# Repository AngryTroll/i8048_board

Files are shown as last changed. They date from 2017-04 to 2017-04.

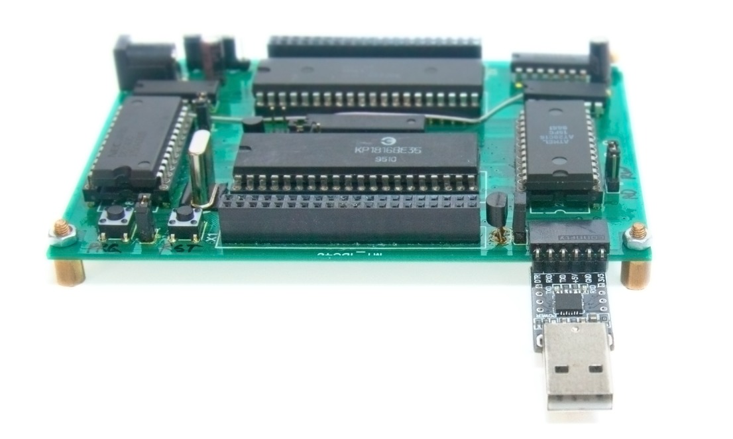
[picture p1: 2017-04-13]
pcad/rev_A/photos/3_1.jpg

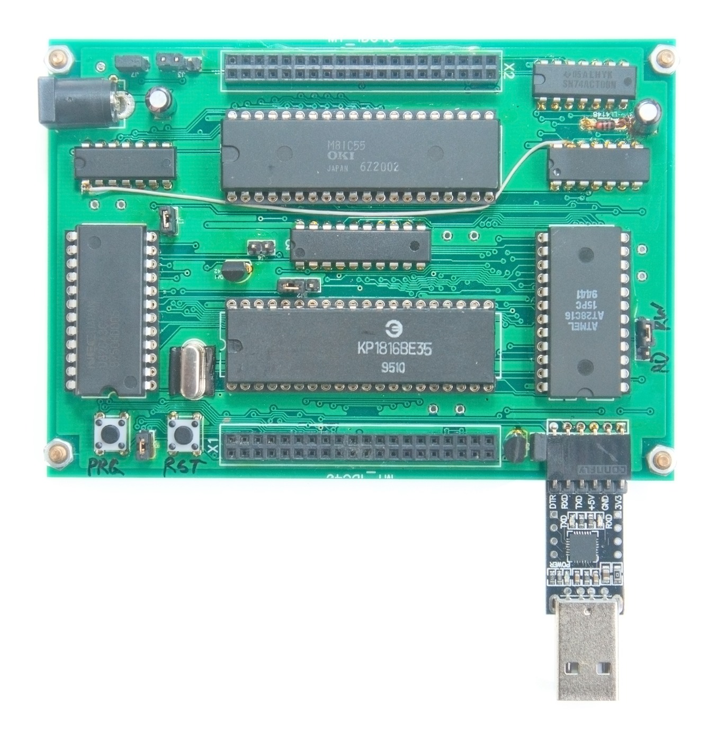
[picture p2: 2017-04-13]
pcad/rev_A/photos/3_3.jpg

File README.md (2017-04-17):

# i8048_board
retro i8048 microcontroller board

directory structure:

pcad/ --  schematics and PCB in pcad2006 format, also contains gerber files (could be viewed by gerbv software) and some photos

sim/ -- simple C simulator, was used for developing of boot software before the board was available

src/ -- some source code, particularly, some tests and serial port python programmer

Features:
 - 8035/8039/8048/8049 (both nmos and cmos) compatible (on the photos there is KP1816BE35 -- soviet clone of 8035 chip)
 
 - IO expander chips: 82(c)43 and 81c55 IO/RAM/timer
 
 - total 12+16+22 = 50 IO pins, one 8bit timer, one 14bit timer, all available at the connectors

 - T0, T1, /INT signals of CPU available at the connectors
 
 - 2K code flash, 256 bytes of movx-RAM. Flash is both hardware and software write-protected

 - usage of 27(c)16 is also possible
 
 - boot code that allows in-system programmability via cheap USB-to-serial converter (/src/boot)
 
 - merged memory, code could be accessed via MOVX command as well as execution from movx-RAM is possible.
   This gives extra flexibility in table accesses as well as allows flash programming during CPU execution.
 
 - 6 MHz (0.4 MIPS) speed
 
 - flexible configurable interrupts from 81c55 timer
 
 - configurable clock source for 81c55 timer
 
 - extra NAND gate and flipflop available at the connectors

 - assembly language tests: 
   * /src/tst_oti: tests pins in output mode and 81c55 timer in square wave generator mode
   * /src/tst_ram: simple PRNG-based memory test
   * (more to come)

 - host programmer software, written in python (/src/host_pgm)

 - Easy shield board developing, prototype boards of different sizes (specifically, 7x9 cm and 8x12 cm) could be used.

 - retro application areas:
   * calculator (with additional shield board)
   * chess player (either with shield board or via serial port)
   * clock/timer with 7-segment or dotted displays
   * (anything imaginable)

Errata:
 - lousy reset circuit that is unable to generate reset at short power outages.
   This connected with the inherent ability of 8035 chips to continue write accesses
   during reset assertions, could easily lead to boot area EEPROM corruption.
 Workaround: deliberately use RO/RW jumper, set RW only during programming operations.

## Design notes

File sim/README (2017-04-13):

simple 8048 simulator,
simulates CPU and uart (softwared of course) from stdin/stdout

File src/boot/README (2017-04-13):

boot to reprogram EEPROM in-system using serial port

"manual":

exchange runs at 9600 baud (6 MHz quartz=2.5us cycle), 8-N-2 (TWO STOP BITS!!!)

1. after reset, if P24=0, go to boot (copy it to RAM, run)
2. boot prints "boot48\n"
3. commands:
   'j' - run main program (from 0x100), interrupts mapped to 0x103, 0x107.
         echoes 'j' back then goes.

   'wHHLLDD' - write to flash at HHLL address, DD - data.
               no write if (addr&0xFFF)<0x100 or >=0x800, goes to step 2.
               Otherwise (write ok) gives 'ok\n' and then step 3.
   'rHHLL' - returns data from given address (0x000..0xFFF), then '\n', then step 2.

all addresses and data is in HEX (big letters)

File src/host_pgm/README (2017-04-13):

host programmer for 8048 board.

written in python, uses pyserial package.

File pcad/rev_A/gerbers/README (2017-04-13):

8048_BOARD.DRL - drill
8048_BOARD.GBL - bottom layer copper
8048_BOARD.GBO - bottom layer silk
8048_BOARD.GBS - bottom layer mask
8048_BOARD.GKO - board outline
8048_BOARD.GTL - top layer copper
8048_BOARD.GTO - top layer silk
8048_BOARD.GTS - top layer mask

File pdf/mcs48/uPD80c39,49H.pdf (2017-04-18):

www.DataSheet4U.com www.DataSheet4U.com www.DataSheet4U.com

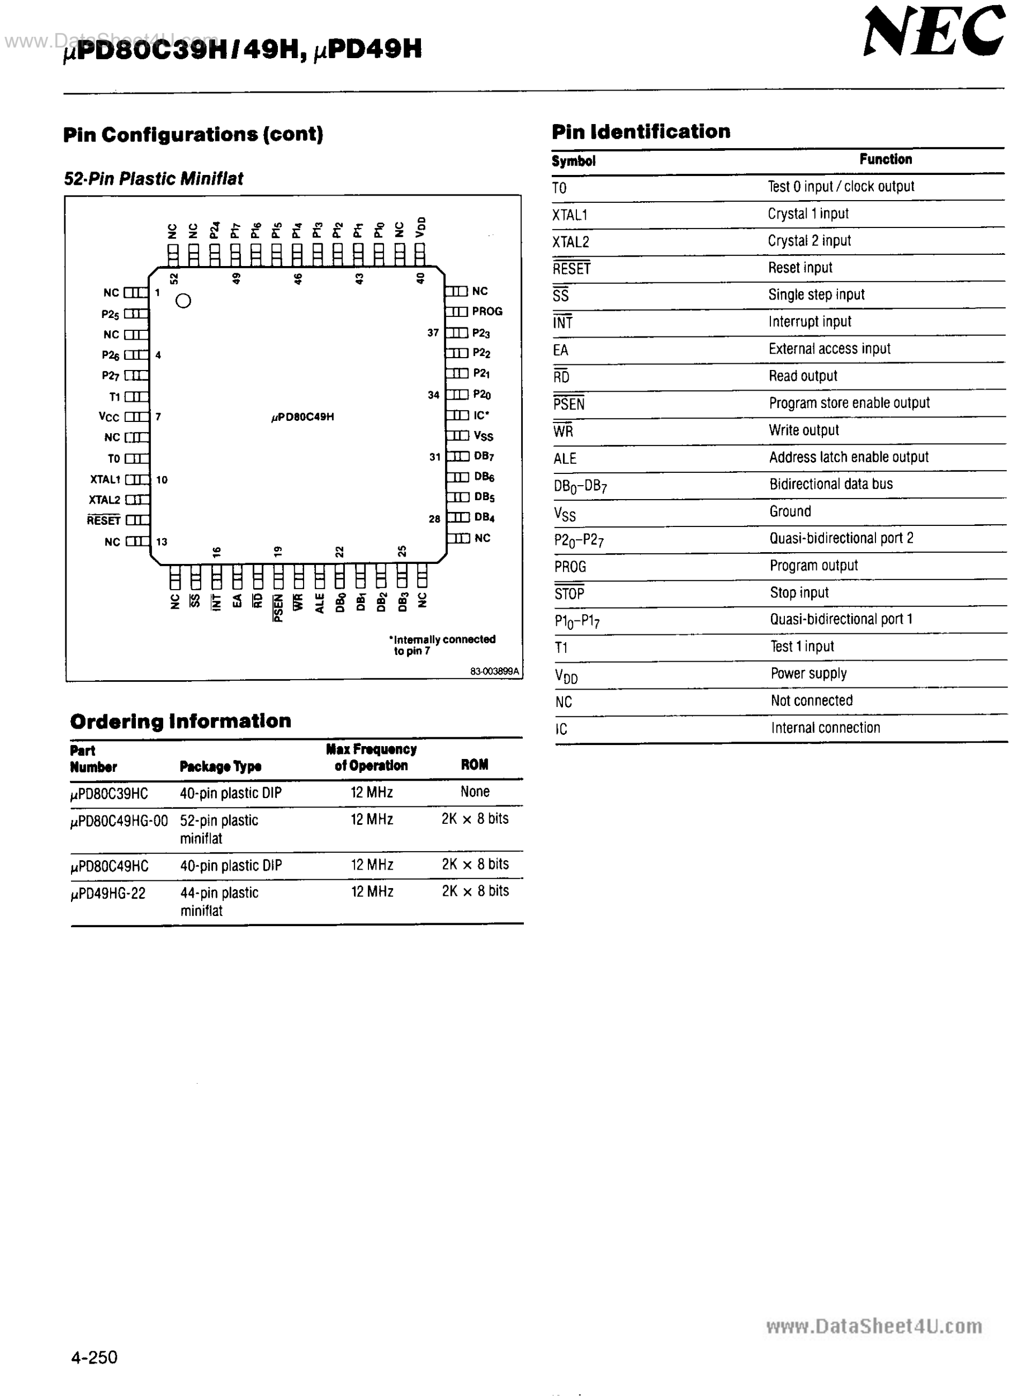
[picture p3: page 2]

www.DataSheet4U.com

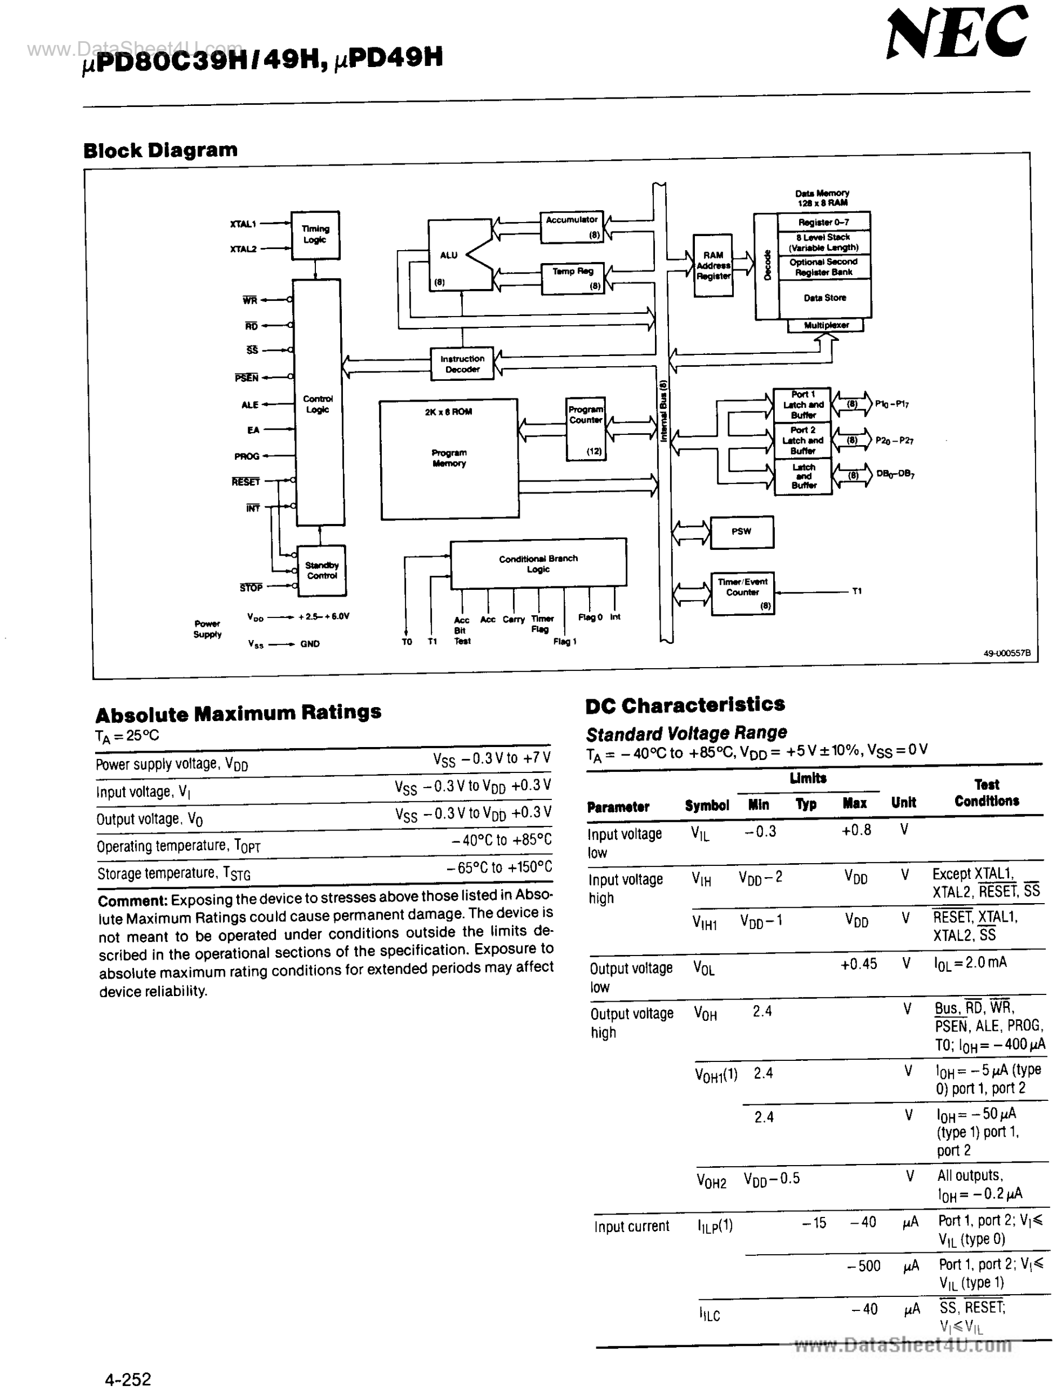
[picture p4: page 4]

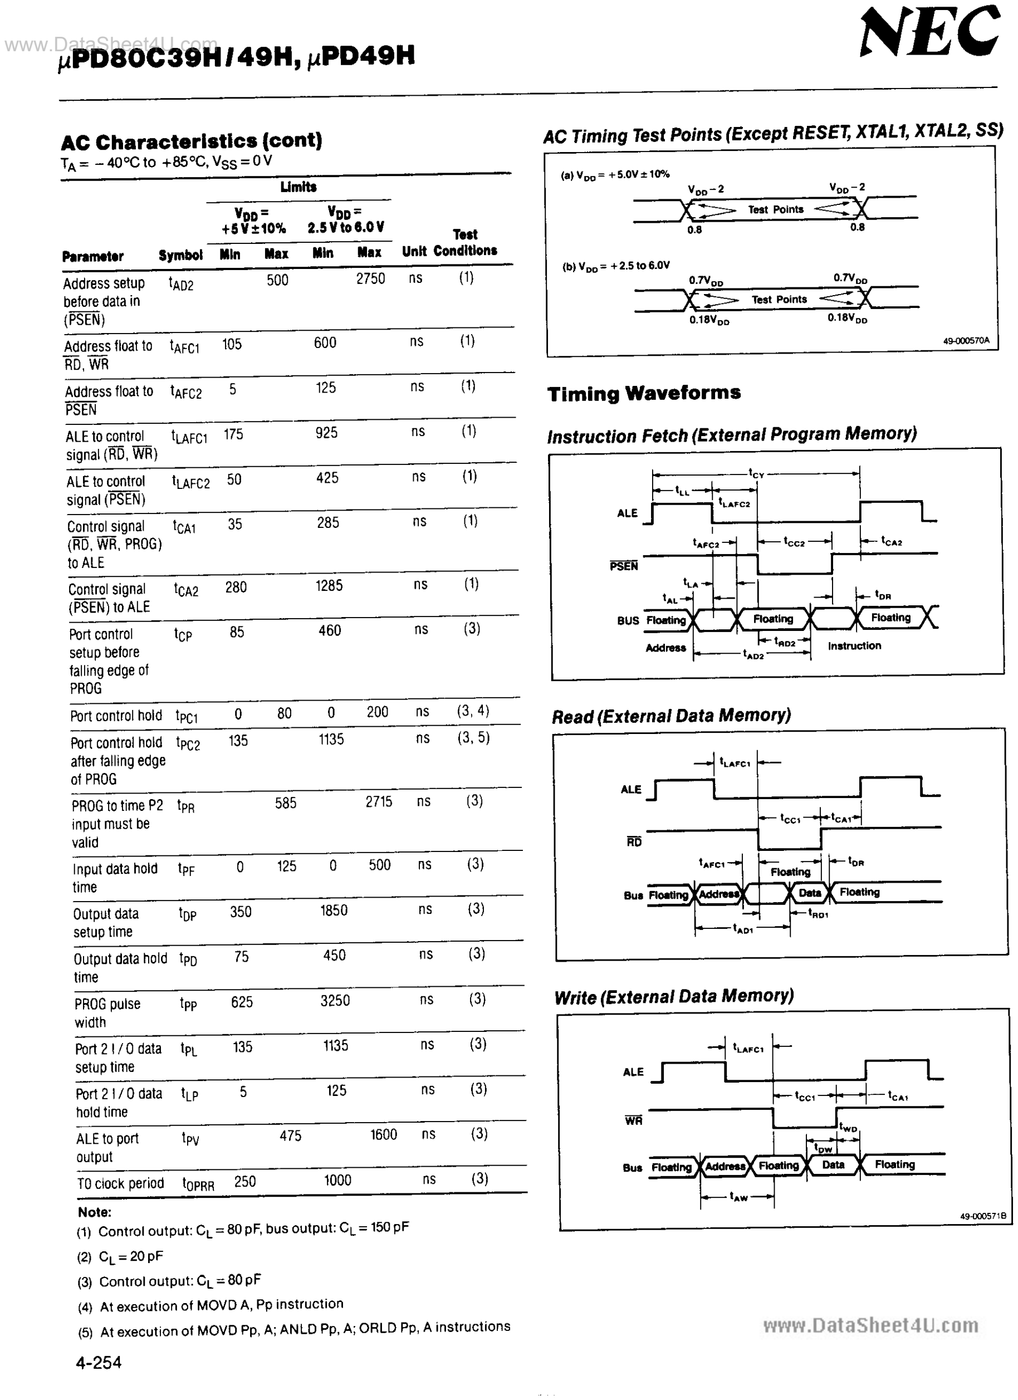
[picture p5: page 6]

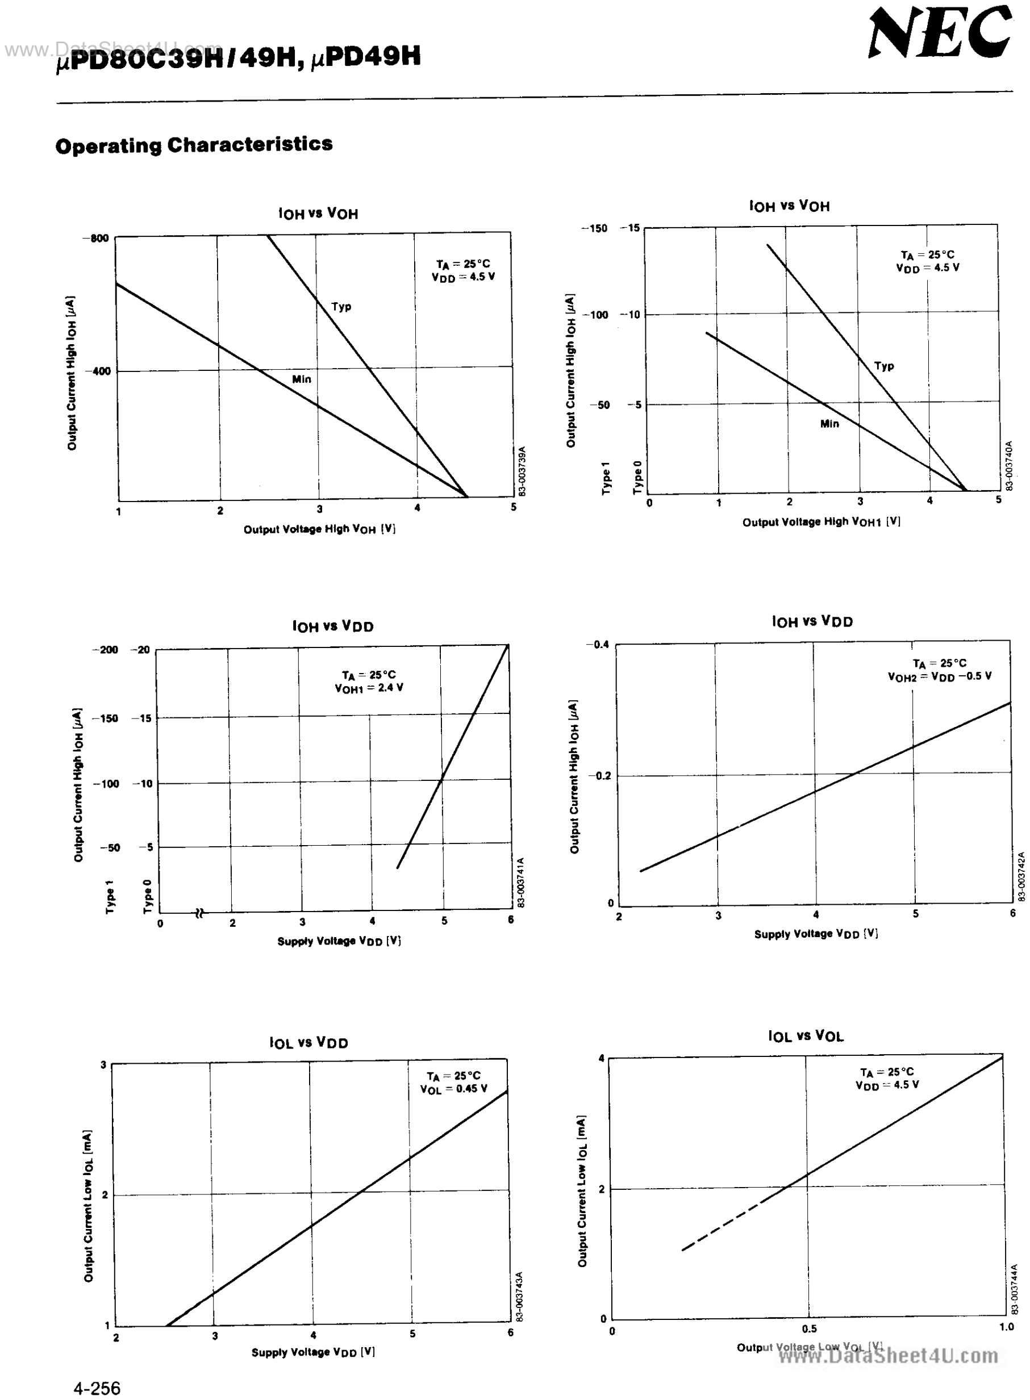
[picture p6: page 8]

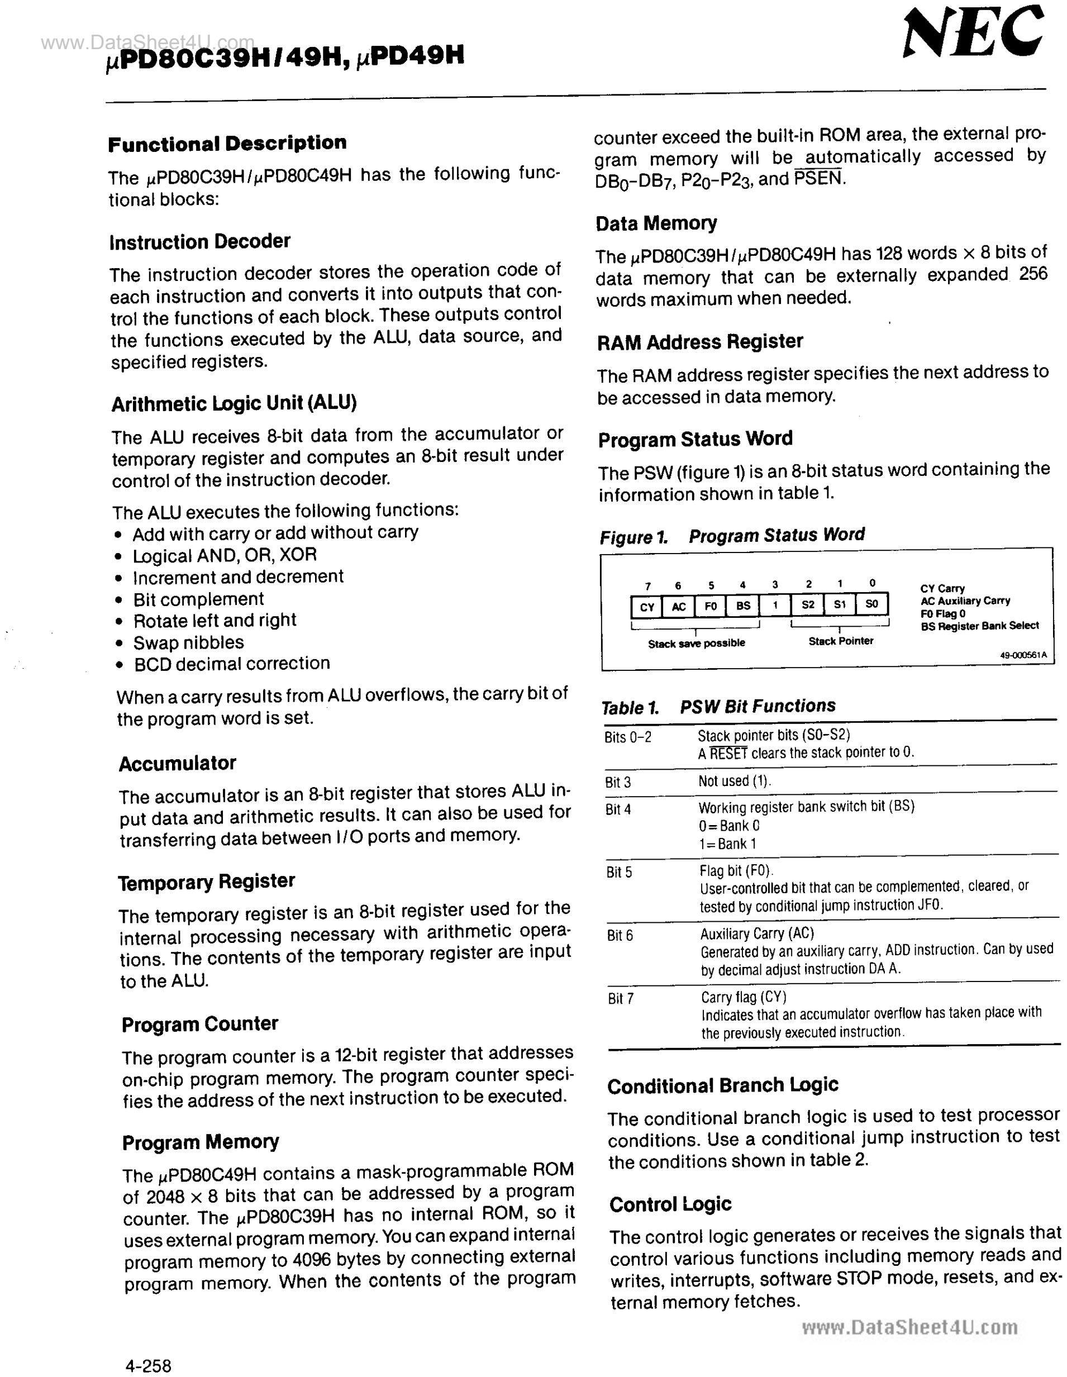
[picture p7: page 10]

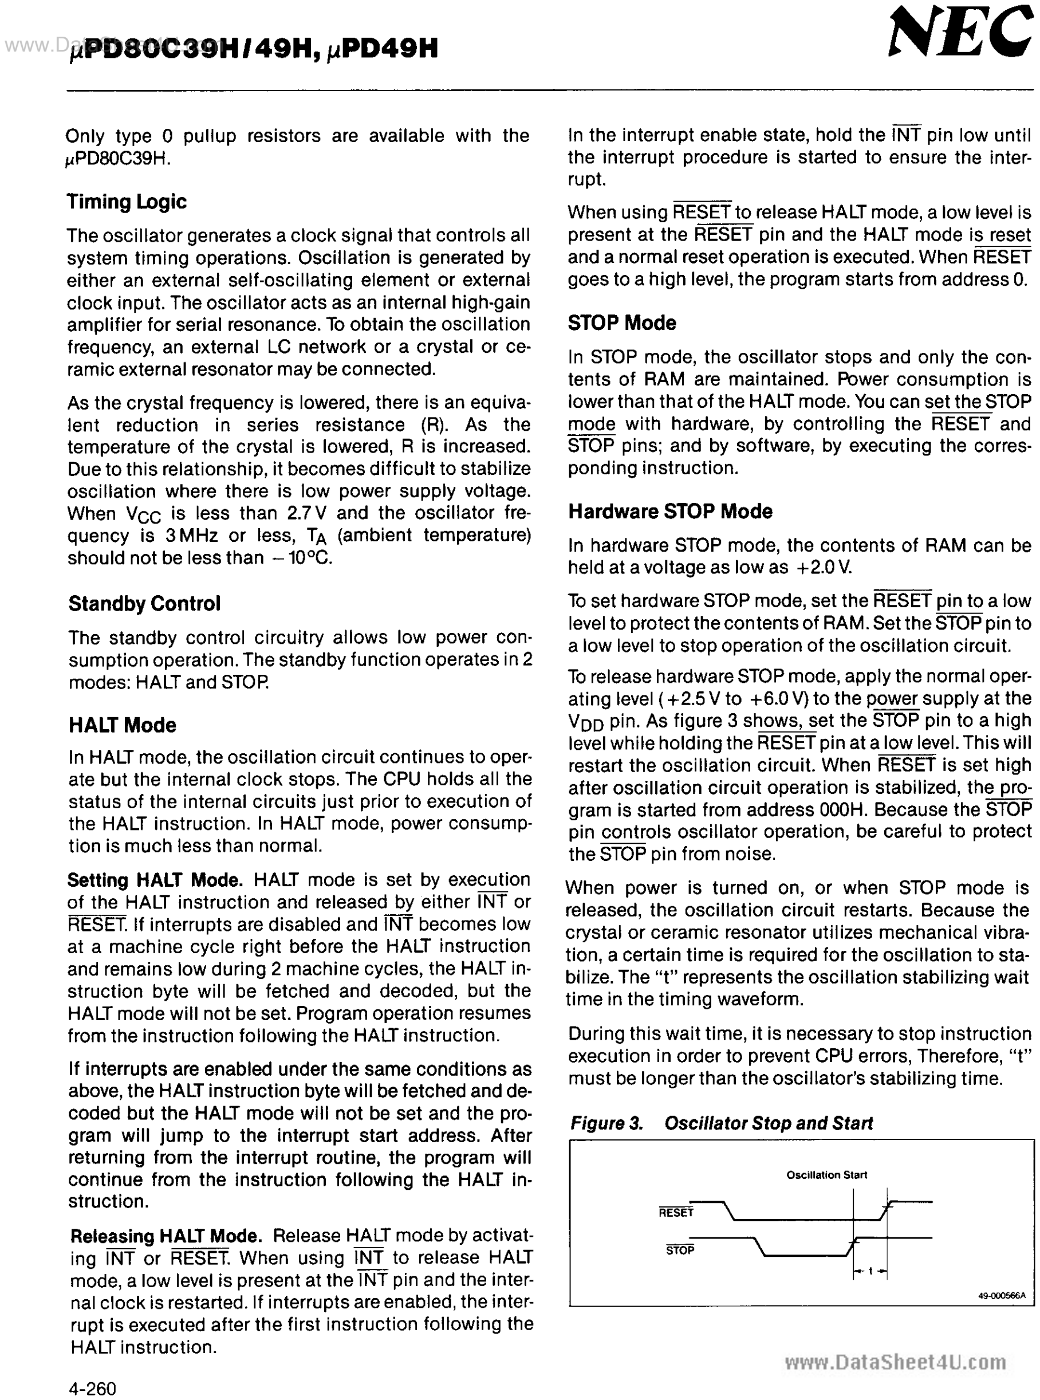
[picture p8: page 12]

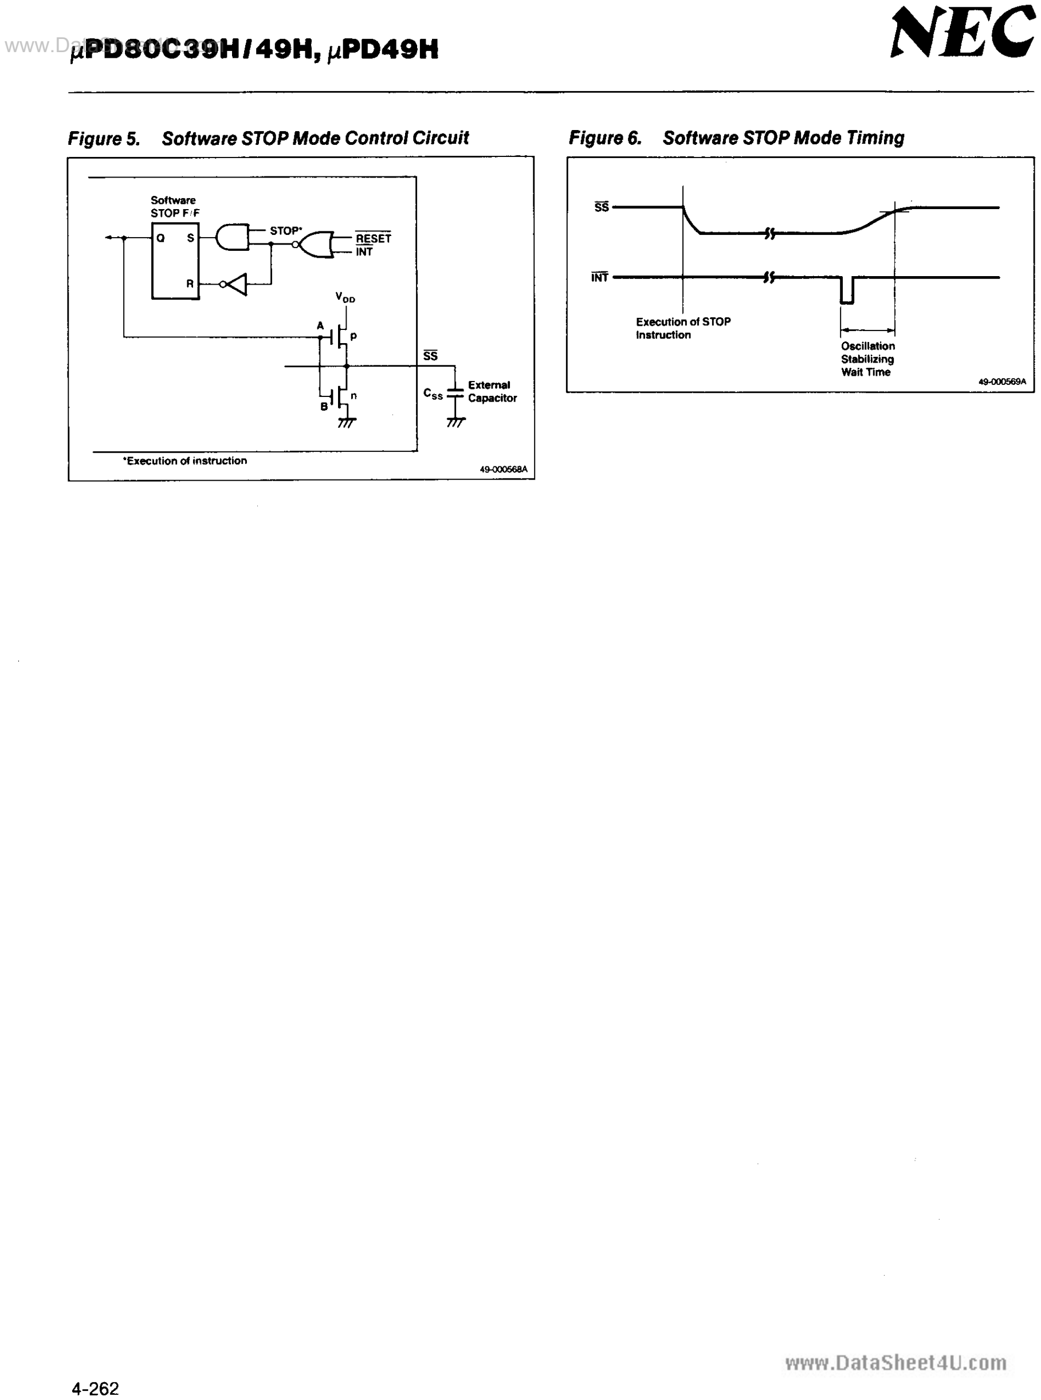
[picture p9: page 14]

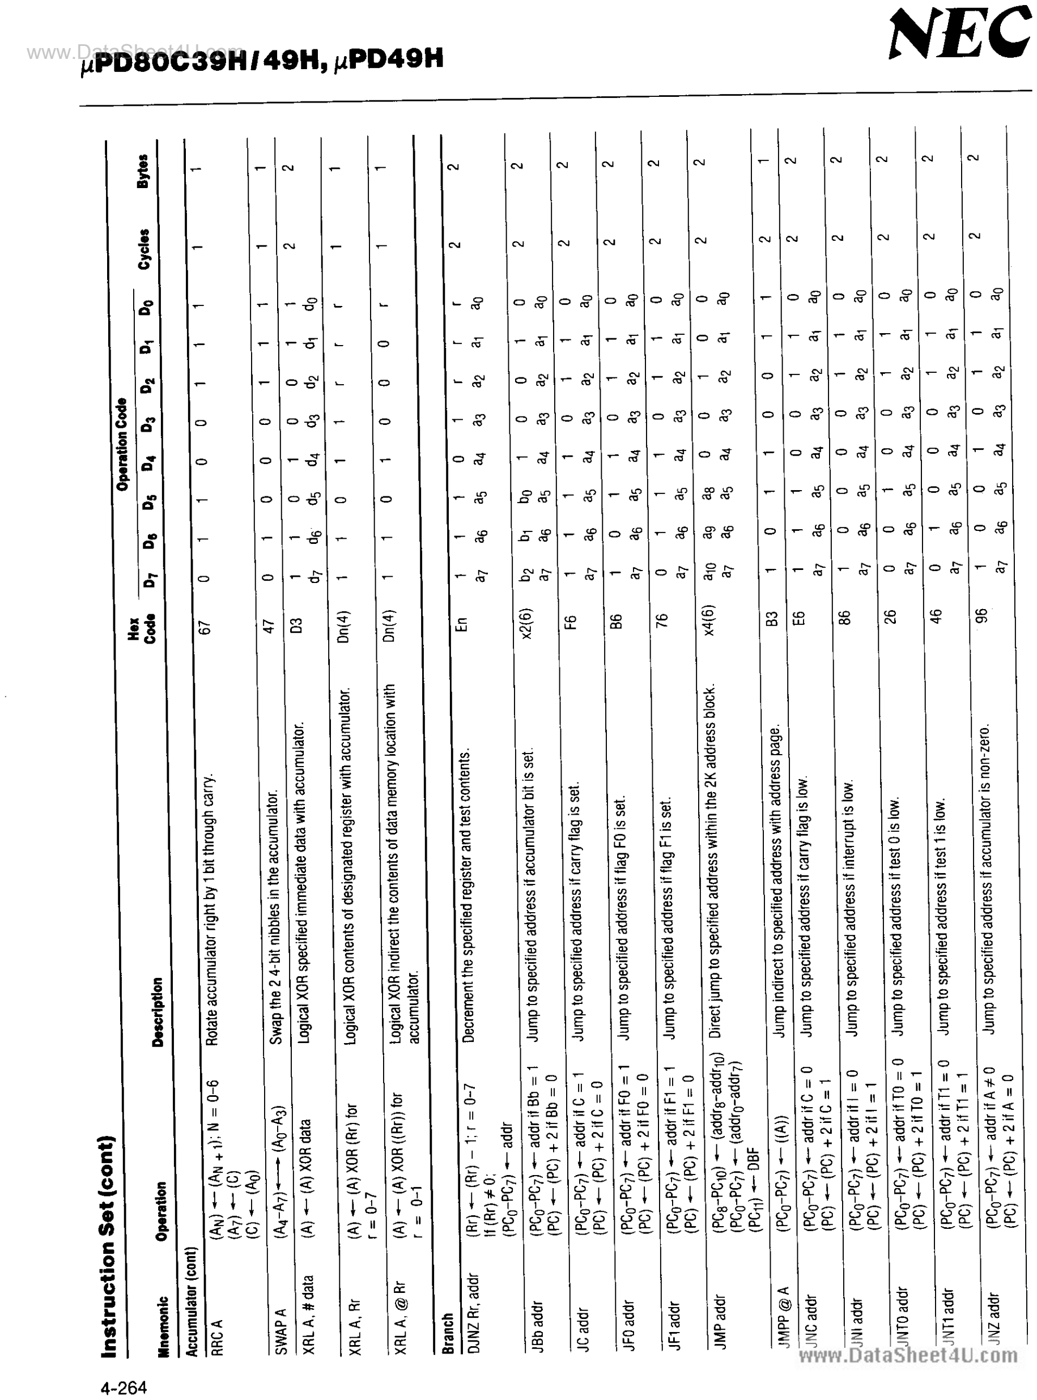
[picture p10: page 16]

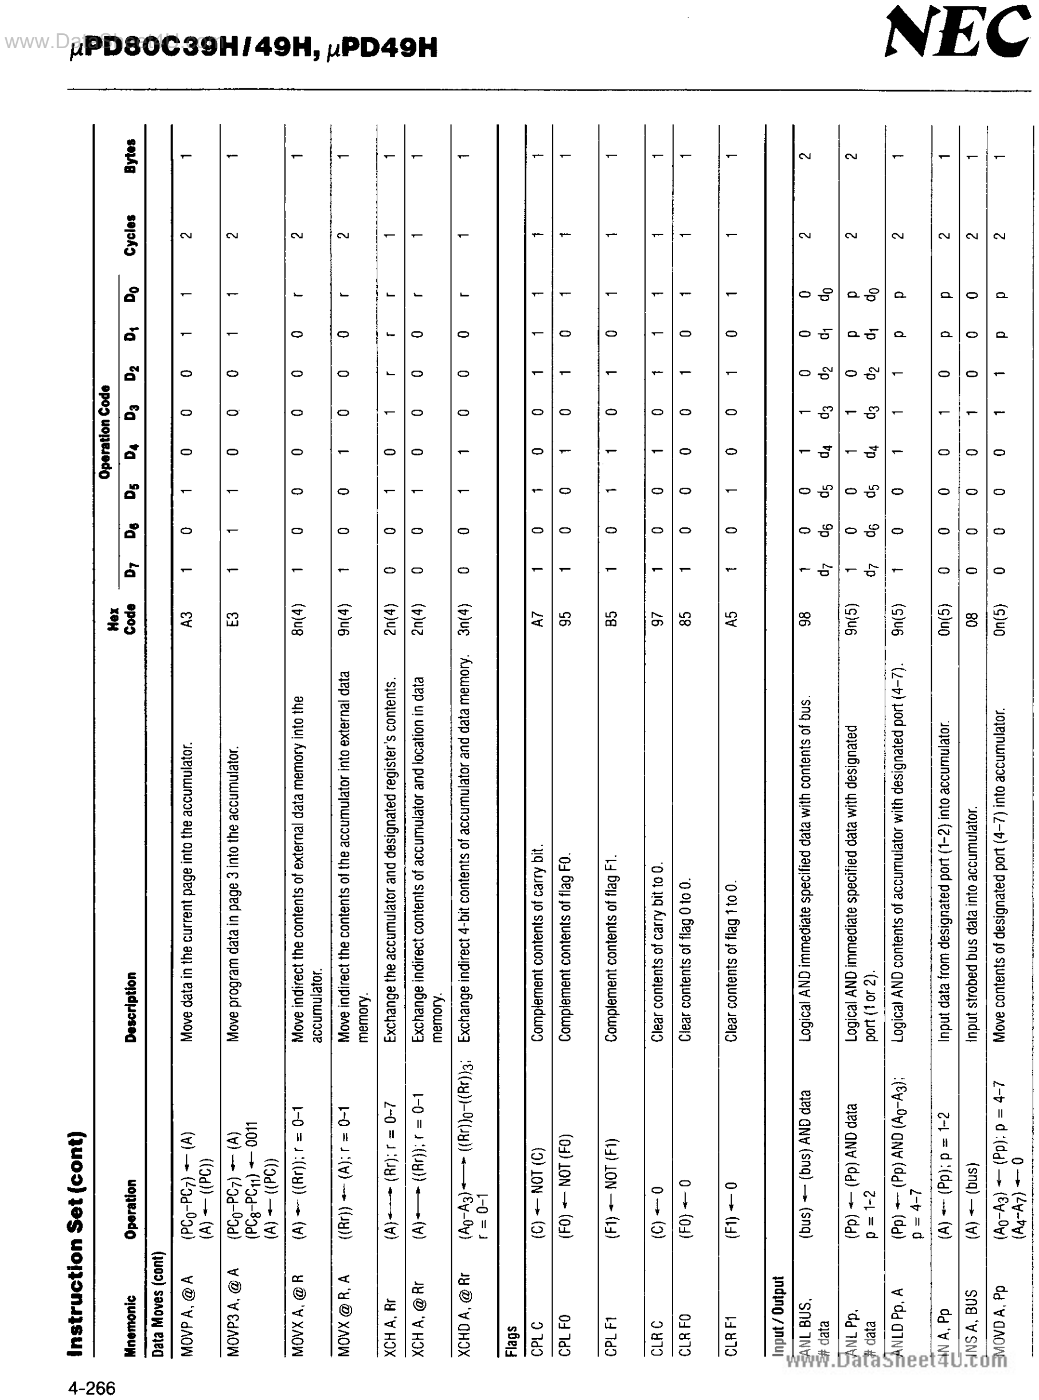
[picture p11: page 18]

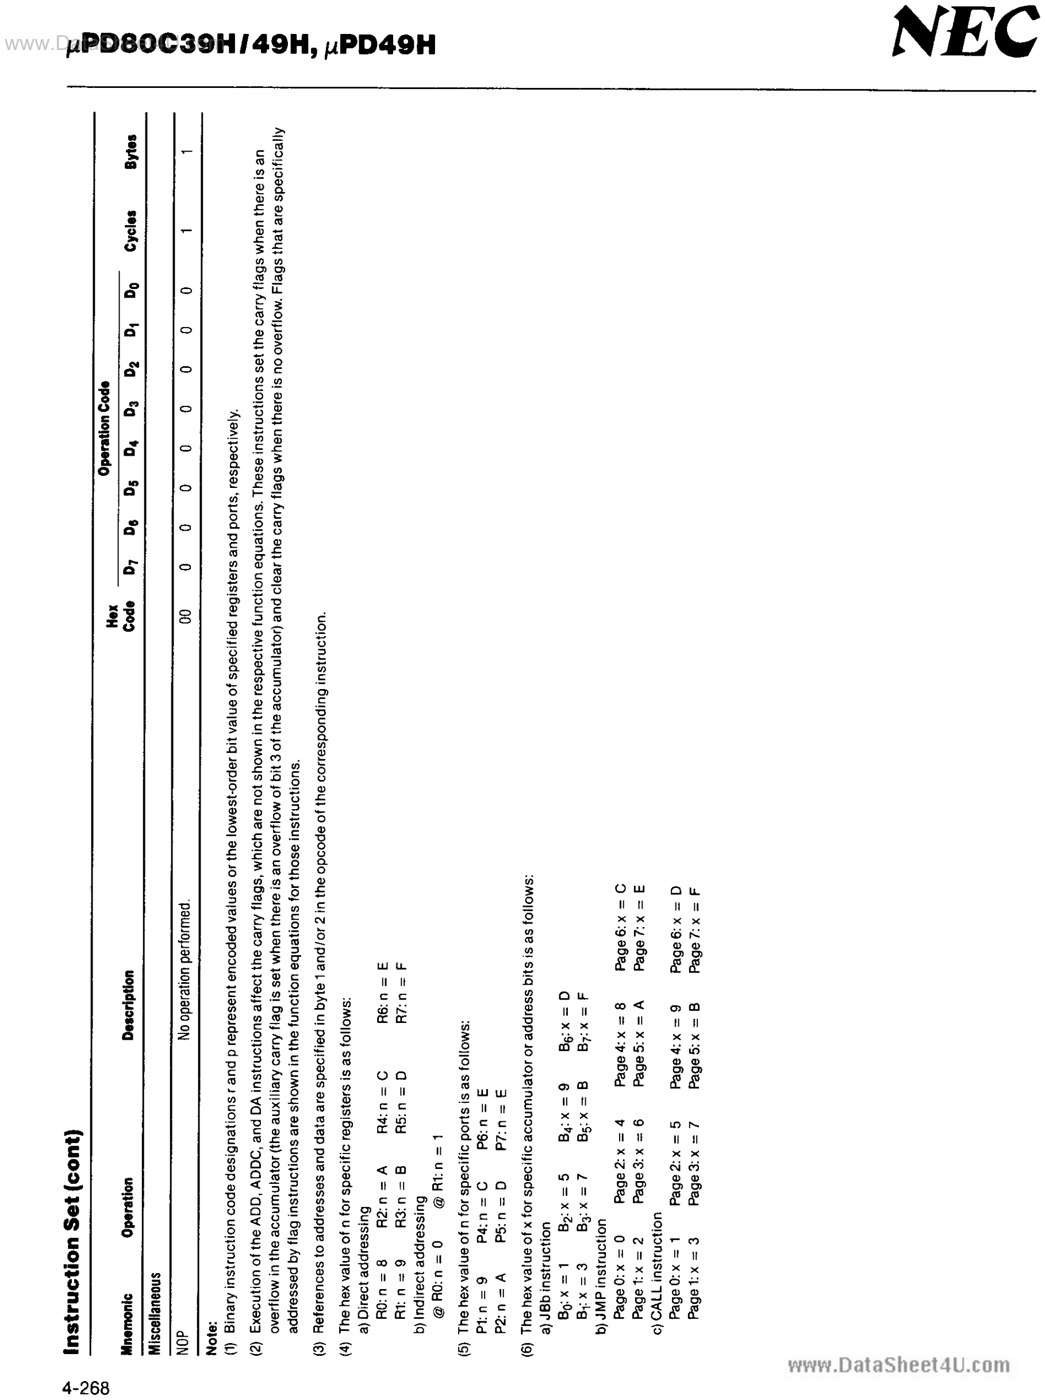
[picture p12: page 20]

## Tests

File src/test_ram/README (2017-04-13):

test for i8048 board.

проверяется:

 - часть внутренней памяти, не используемая для хранения переменных
 - внешняя память (256 байт), с адреса 0x0800 (0x0800..0x08FF).

используется: печать байтов со скоростью 9600 из бута.

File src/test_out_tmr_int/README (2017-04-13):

test for i8048 board.

проверяется:

 - все доступные IO пины в режиме выхода
 - внутренний таймер 8048, прерывание от него
 - таймер 8155, генерация им меандра, прерывание от этого меандра (посредством половинки тм2)
 - вывод клока с пина T0 на внешний таймер

НЕ проверяется:
 - ввод клока на T1
 - пины в режиме входа

паттерн на ИО пинах:

1. выводится вектор 111...1111 (все единицы) на все пины в режиме выхода
2. через этот вектор прогоняется бегущий ноль
3. выводится вектор 'все нули' и через него прогоняется бегущая единичка
4. некоторое время выводятся чередующиеся векторы 10101010...1010 и 01010101...0101
5. некоторое время выводятся рандомные векторы
6. повтор

проверка внутреннего таймера и его прерываний:
по прерыванию меняется вектор на выходных пинах.

проверка внешнего таймера -- осциллографом.
изменение периода внешнего таймера -- по прерыванию на /INT

требуемая конфигурация джамперов на плате:

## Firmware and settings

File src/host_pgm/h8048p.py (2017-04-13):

#!/usr/bin/python3
#
# host programmer for 8048 retro board.
# uses pyserial package.

import io,sys,argparse
import serial
import time











# arguments parser based on argparse package
#
# -r  -- just reset the board using DTR signal, other args are ignored. -j can be added to send 'j' afterwards.
# -nr -- do not reset board with DTR before programming. test for 'boot48' string will be executed anyway,
#        test must pass to continue programming. Default is reset board before programming.
# -nv -- do not commit verification pass after all data is programmed. Default is to perform verification.
# -b  -- switch to binary mode. Default is intelhex mode, when addresses are defined by ihex file and are inside --offs and --size bounds.
#        for binary files, data is always taken from the very beginning of the file and placed from --offs to the ROM, up to --size bytes.
# -j  -- Send 'j' command to the bootloader, which causes it to run ROM from the address 0x100 (main firmware). Default is to leave the device
#        in bootloader.
#
#
#
#
#
#
#
#
#
#
def argument_parser():

	def auto_int(x):
		return int(x,0)
	
	
	parser=argparse.ArgumentParser()

	parser.add_argument('-r',  action='store_true', help='Just reset the board using DTR signal, all other arguments will be ignored')
	parser.add_argument('-nr', action='store_true', help='Do not reset the board with DTR before actual action starts. Default is resetting the board')
	parser.add_argument('-nv', action='store_true', help='Do not verify the written data just after the programming. Default is to verify everything programmed')
	parser.add_argument('-b',  action='store_true', help='Switch to binary mode. Default is intelhex mode. Binary file is always used from the beginning, while intelhex is used according to addresses within.')
	parser.add_argument('-j',  action='store_true', help='Perform \'j\' command (run ROM from 0x100) just after read/write actions are finished. Default is no \'j\', device is left in programming mode.')

	parser.add_argument('--offs', action='store', type=auto_int, default=256,  help='Offset inside ROM. Default is 0x100. Addresses 0x000-0x0FF couldn\'t be written.')
	parser.add_argument('--size', action='store', type=auto_int, default=1792, help='Size to use from the offset. Default is 0x700.')

	parser.add_argument('--read',  action='store', help='File to read the contents of the ROM into. Executed before --write')
	parser.add_argument('--write', action='store', help='File to write to the ROM. Executed after --read')
	parser.add_argument('--check', action='store', help='File to check against ROM contents. Exclusive with both --read and --write')

	parser.add_argument('--port', action='store', help='Serial port to open')

	args=parser.parse_args()

	return args


# just simple args validator
def validate_args(args):

	if args.port==None:
		sys.stderr.write('serial port not given!\n')
		sys.exit(1)

	if args.r==True:
		return

	if args.check==None and args.read==None and args.write==None and args.j==False:
		sys.stderr.write('nothing to do!\n')
		sys.exit(1)

	if args.check!=None and ( args.read!=None or args.write!=None ):
		sys.stderr.write('--check arg must be exclusive with both --read and --write!\n');
		sys.exit(1)

	if args.offs<(0 if args.write==None else 256) or (args.offs+args.size)>2048:
		sys.stderr.write('combination of --offs and --size goes out of allowed range!\n');
		sys.exit(1)

	if args.size<1:
		sys.stderr.write('--size is less than 1!\n')
		sys.exit(1)

	return
	


# perform tasks required by args
def perform(args,rd_file,wr_file,chk_file):


	# parse input file (if any)
	if wr_file!=None or chk_file!=None:
		write_data = parse_write_file(args.b,args.offs,args.size,(chk_file if chk_file!=None else wr_file))


	# open serial port
	serport = serial.Serial()
	#
	serport.port = args.port
	serport.baudrate = 9600
	serport.bytesize = serial.EIGHTBITS
	serport.parity   = serial.PARITY_NONE
	serport.stopbits = serial.STOPBITS_TWO
	serport.timeout  = 0.1
	serport.xonxoff  = False
	serport.rtscts   = False
	serport.dsrdtr   = False
	#
	if args.r==True:
		dtr = 1 # make reset
	elif args.nr==True:
		dtr = 0 # don't make reset
	else:
		dtr = 1 # make reset
	#
	try:
		serport.open()
	except serial.serialutil.SerialException:
		sys.stderr.write('can\'t open serial port!\n')
		sys.exit(1)

	if dtr==1:
		print('Resetting 8048 board...')

	serport.setDTR(True if dtr==0 else False)


	# now port is opened, if dtr was 1 (reset activated), wait at least 0.1 s by timeouting read().
	# assuming that no read data arrives while dtr=1!

	if dtr==1:
		while len(serport.read(size=256))>0:
			pass

	# at least, 0.1 s (serport.timeout) is passed now (in case of no -nr argument), release dtr and continue with the task
	serport.setDTR(True)


	# check whether boot is working (check for 'boot48' reply)
	if args.r==False or args.j==True:
		check_boot_connection(serport)


	# do read task, if needed
	if args.r!=True and (args.read!=None or args.check!=None):
		read_data = read_contents(serport,args.offs,args.size)
	else:
		read_data = None


	# do write task, if needed
	if args.r!=True and args.write!=None:
		program_contents(serport,write_data)


	# do verify task, if needed
	if args.r!=True and args.write!=None and args.nv!=True:
		verify_contents(serport,write_data)

	# do check task, if needed
	if args.r!=True and args.check!=None:
		compare_contents(write_data,read_data)


	# do 'j' command if needed
	if args.j==True:
		serport.write(b'j')
		
		r=serport.read(size=1)
		if len(r)!=1 or r!=b'j':
			sys.stderr.write('warning: sending \'j\' command failed: no response!')
	
	# close port
	serport.close()


	# writeback read file, if needed
	if args.r!=True and args.read!=None:
		write_contents(args.b,args.offs,args.size,read_data,rd_file)


	print('Success!')




# checks wheter boot firmware is functioning.
def check_boot_connection(serport):
	
	#first see if we've already received (or just receiving) 'boot48' string

	boot48 = serport.read(size=256)

	if len(boot48)<7:
		#nothing or crap received: it is possible when we are not resetting board. So then send some 'bad' string, which will cause board to send 'boot48' again
		serport.write(b'\n')
		boot48 = serport.read(size=256)

	if len(boot48)<7 or len(boot48)>8 or boot48[:6]!=b'boot48':
		#size of 'boot48' is 6 bytes, plus 1 or 2 lineend bytes. Otherwise, crap is certainly received, which is unrecoverable
		sys.stderr.write('can\'t communicate with boot firmware!\n')
		sys.exit(1)



################################################################################
# parse file to be written to flash.
def parse_write_file(b,offs,size,filehandle):


	write_contents = []


	if b==True: # binary file

		try:
			array = filehandle.read()
		except (OSError,IOError):
			sys.stderr.write("can't read data from --write or --check file!\n")
			sys.exit(1)

		file_size = len(array)

		if file_size<1:
			sys.stderr.write("--write or --check file has zero length!\n")
			sys.exit(1)

		my_size=min(size,file_size)

		j=0
		for i in range(offs,offs+my_size):
			write_contents.append((i,array[j]))
			j=j+1

	else: # ihex file
		sys.stderr.write("intelhex yet not supported\n")
		sys.exit(1)


	return write_contents

# reads data from ROM
def read_contents(ser,offs,size):

	print('Reading data from boot48...')


	read_data = []

	for i in range(offs,offs+size):

		addr='r{0:04X}'.format(i)
		baddr=bytes(addr,'utf-8')
		ser.write(baddr)

		result=ser.read(size=3) # read answer

		if len(result)!=3:
			sys.stderr.write("error parsing reply to read command!\n")
			sys.exit(1)

		try:
			byte=int(result[0:2],16)
		except ValueError:
			sys.stderr.write("error parsing reply to read command!\n")
			sys.exit(1)
	

		read_data.append((i,byte))

	return read_data

# writes data to file
def write_contents(b,offs,size,read_data,rd_file):


	if b==True: # binary file

		#assume that read_data is sequential (has no holes)

		b=bytearray(1)

		for i in read_data:
			
			b[0] = i[1]

			rd_file.write(b)


	else: # intelhex
		sys.stderr.write("intelhex yet not supported\n")
		sys.exit(1)
		

# programs data to ROM
def program_contents(ser,write_data):

	print('Programming data to boot48...')
	
	
	for el in write_data:

		(addr,data)=el

		wrcmd='w{0:04X}{1:02X}'.format(addr,data)
		bwrcmd=bytes(wrcmd,'utf-8')

		ser.write(bwrcmd)

		result=ser.read(size=3)

		if len(result)!=3 or result!=b'ok\n':
			sys.stderr.write("error parsing reply to write command!\n")
			sys.exit(1)

# verify ROM contents against data previously written
def verify_contents(ser,write_data):

	print('Verifying data just written to boot48...')


	for el in write_data:

		(addr,data)=el

		rdcmd='r{0:04X}'.format(addr)
		brdcmd=bytes(rdcmd,'utf-8')

		ser.write(brdcmd)

		result=ser.read(size=3)

		if len(result)!=3:
			sys.stderr.write("error parsing reply to verify command!\n")
			sys.exit(1)

		try:
			byte=int(result[0:2],16)
		except ValueError:
			sys.stderr.write("error parsing reply to verify command!\n")
			sys.exit(1)

		if byte!=data:
			sys.stderr.write("First verify error at {0:04X}: must be {1:02X}, was {2:02X}!\n".format(addr,data,byte))
			sys.exit(1)


################################################################################
#
###################
# main() function #
###################
#
def main():

	args=argument_parser()
	print(args)
	validate_args(args)



	# opening files, if given
	read_file=None
	write_file=None
	check_file=None
	#
	if args.read!=None:
		try:
			read_file = open(args.read,('wt' if args.b==False else 'wb'))
		except (OSError,IOError):
			if read_file==None:
				sys.stderr.write('can\'t open --read file!\n')
				sys.exit(1)
	
	if args.write!=None:
		try:
			write_file = open(args.write,('rt' if args.b==False else 'rb'))
		except (OSError,IOError):
			if write_file==None:
				sys.stderr.write('can\'t open --write file!\n')
				sys.exit(1)

	if args.check!=None:
		try:
			check_file = open(args.check,('rt' if args.b==False else 'rb'))
		except (OSError,IOError):
			if check_file==None:
				sys.stderr.write('can\'t open --check file!\n')
				sys.exit(1)




	perform(args,read_file,write_file,check_file)




	# close files
	if read_file!=None:
		read_file.close()
	if write_file!=None:
		write_file.close()
	if check_file!=None:
		check_file.close()

	sys.exit(0)

if __name__=='__main__':
	main()

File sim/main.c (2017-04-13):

#include <stdio.h>
#include <stdlib.h>
#include <stdint.h>
#include <string.h>
#include <fcntl.h>
#include <unistd.h>
#include <errno.h>

#include "ihexread.h"
#include "cpu8048.h"

#define ROM_SIZE 2048
#define EXT_SIZE 256

uint8_t ROM[2048];
uint8_t EXT[256];

struct state_48 s;


#define UART_SNDBF_SIZE 256
#define UART_SNDBF_MASK 255

volatile uint8_t uart_sndbf[UART_SNDBF_SIZE];

volatile unsigned int uart_sndbf_head=0;
volatile unsigned int uart_sndbf_tail=0;


volatile uint8_t uart_send_bit;


void uart_recv(unsigned int cycle, uint8_t bit);
uint8_t uart_send(unsigned int cycle);

int uart_try_send(char *);
void uart_poll_stdin(void);

int main(int argc, char ** argv)
{
	int i;
	FILE * hex;


	for(i=0;i<ROM_SIZE;i++)
		ROM[i] = 0x01;
	//
	ROM[0] = 0x24; ROM[1] = 0x00; // jmp $100
	ROM[3] = 0x24; ROM[4] = 0x03; // jmp $103
	ROM[7] = 0x24; ROM[8] = 0x07; // jmp $107


	if( argc<=1 )
	{
		printf("please give argument!\n");
		exit(1);
	}

	hex=fopen(argv[1],"r");
	if( !hex )
	{
		printf("%s(): can't open hex file %s!\n",__func__,argv[1]);
		exit(1);
	}
	ihex_read(hex,ROM,0,2048);


	fcntl(0, F_SETFL, fcntl(0, F_GETFL) | O_NONBLOCK);


	// start execution
	reset_48(&s);
	//
	while(1)
	{
		if( argc<=2 ) dump_48(&s, stderr);
		step_48(&s);
		uart_recv(s.cycle_count, (s.port_latches[2]&0x40));
		uart_send_bit = uart_send(s.cycle_count);

		uart_poll_stdin();
	}








	fclose(hex);

	return 0;
}



uint8_t read_rom_48(uint16_t addr)
{
	if( 0<=addr && addr<ROM_SIZE )
		return ROM[addr];
	else if( ROM_SIZE<=addr && addr<(ROM_SIZE+EXT_SIZE) )
		return EXT[addr-ROM_SIZE];
	else
	{
		printf("%s(): invalid address %x\n",__func__,addr);
		exit(1);
	}
}

uint8_t read_ext_48(uint16_t addr)
{
	if( 0<=addr && addr<ROM_SIZE )
		return ROM[addr];
	else if( ROM_SIZE<=addr && addr<(ROM_SIZE+EXT_SIZE) )
		return EXT[addr-ROM_SIZE];
	else
	{
		printf("%s(): invalid address %x\n",__func__,addr);
		exit(1);
	}
}

void    write_ext_48(uint16_t addr, uint8_t data)
{
	if( ROM_SIZE<=addr && addr<(ROM_SIZE+EXT_SIZE) )
	{
		EXT[addr-ROM_SIZE]=data;
	}
	else if( 0<=addr && addr<ROM_SIZE )
	{
//		printf("%s(): ROM write addr=%04x, data=%02x\n",__func__,addr,data);
	}
	else
	{
		printf("%s(): invalid address %x\n",__func__,addr);
		exit(1);
	}
}


void set_dir(unsigned int cycle_count, uint8_t port, uint8_t data)
{}

void out_port(unsigned int cycle_count, uint8_t port, uint8_t data)
{
	if( port==2 )
	{
//printf("%s(): data=%02x\n",__func__,data);
		//uart_recv(cycle_count, (data&0x40));
	}
}

uint8_t in_port(unsigned int cycle_count, uint8_t port)
{
	uint8_t val;

	val = s.port_latches[port];
	
	if( port==2 )
	{
		//return uart_send_bit ? 0xEF : 0x6F; // RxD is bit 7, /PROG is bit 4
		val &= (uart_send_bit ? 0xEF : 0x6F);
	}

	return val;
}



// UART receive at 9600 baud (41 2/3 cycles per bit)
void uart_recv(unsigned int curr_cycle, uint8_t curr_bit) // input is cycle count and TxD bit (1 or 0)
{
	static int init = 1;

	static unsigned int prev_cycle;
	static uint8_t prev_bit;

	const float BAUD_TIME = (41.66666666666666666666666666);


/*	static int state;
	const int ST_IDLE=0;
	const int ST_STRT=1;
	const int ST_BITS=2;
	const int ST_STOP=3;
*/
	static enum { ST_IDLE, ST_STRT, ST_BITS, ST_STOP } state;


	static int uart_cycles;
	static int bitcount;
	static int word;


	unsigned int cycle;
	uint8_t bit;


	if( init )
	{
		prev_cycle = curr_cycle;
		init = 0;
		state = ST_IDLE;
	}


//printf("%s(): cycle=%d, bit=%02x\n",__func__,curr_cycle,!!curr_bit);


	if( curr_cycle==prev_cycle )
	{
		prev_bit = curr_bit;
		return;
	}



	cycle = init ? 0 : 1;
	init = 0;

	while( cycle<=(curr_cycle-prev_cycle) )
	{
		bit = (cycle==(curr_cycle-prev_cycle)) ? curr_bit : prev_bit;
//printf("%s(): cycle=%d, bit=%02x, state=%d\n",__func__,cycle,bit,state);
		switch(state)
		{
		case ST_IDLE:
			if( !bit )
			{
				uart_cycles=0;
				state=ST_STRT;
			}
		break;
		case ST_STRT:
			uart_cycles++;
			if( uart_cycles>=(BAUD_TIME/2.0) )
			{
				if( bit ) // wrong start bit
				{
					state = ST_IDLE;
//printf("%s(): wrong start bit!\n",__func__);
				}
				else // start bit OK
				{
					state = ST_BITS;
					bitcount = 1;
					word = 0;
				}
			}
		break;
		case ST_BITS:
			uart_cycles++;
			if( uart_cycles>=(BAUD_TIME*(0.5+bitcount)) )
			{
				bitcount++;
				// collect bits
				word >>= 1;
				word |= bit ? 0x80 : 0;

				if( bitcount>=9 )
				{
					state = ST_STOP;
				}
			}
		break;
		case ST_STOP:
			uart_cycles++;
			if( uart_cycles>=(BAUD_TIME*9.5) )
			{
				if( bit ) // stop bit OK
				{
					fprintf(stdout,"%c",word);fflush(stdout);
				}
//else printf("%s(): wrong stop bit!\n",__func__);

				state = ST_IDLE;
			}
		break;
		default:
		break;
		}

		cycle++;
	}
//printf("%s(): end of while loop\n",__func__);


	prev_cycle = curr_cycle;
	prev_bit   = curr_bit;
}


uint8_t uart_send(unsigned int curr_cycle)
{ // sends bytes from uart_sndbuf. called as CPU inputs from uart pin, returns its required state (0 or !0)

	static int init = 1;

	static unsigned int prev_cycle;

	const float BAUD_TIME = (41.66666666666666666666666666);

	static enum { ST_IDLE, ST_STRT, ST_BITS, ST_STOP } state;

	static int uart_cycles;
	static int bitcount;
	static int word;

	unsigned int cycle;
	static uint8_t bit=1;

	if( init )
	{
		prev_cycle = curr_cycle;
		init = 0;
		state = ST_IDLE;
		bit = 1;
	}

	cycle = init ? 0 : 1;
	init = 0;

	while( cycle<=(curr_cycle-prev_cycle) )
	{
//printf("%s(): cycle=%d, bit=%02x, state=%d\n",__func__,cycle,bit,state);
		switch(state)
		{
		case ST_IDLE:
			// see if there are bytes to send
			if( uart_sndbf_head!=uart_sndbf_tail )
			{
				word = uart_sndbf[uart_sndbf_tail];
				uart_sndbf_tail = (uart_sndbf_tail>=(UART_SNDBF_SIZE-1)) ? 0 : (uart_sndbf_tail+1);
				bitcount = 1;
				state = ST_BITS;
				uart_cycles=0;
				bit = 0;
//printf("%s(): got byte to send: %c\n",__func__,word);
			}
		break;
		case ST_BITS:
			uart_cycles++;
			if( uart_cycles>=(BAUD_TIME*((float)bitcount)) )
			{
				bitcount++;
				
				bit = (word&1);
				word >>= 1;
				word |= 0x80;

				if( bitcount>=11 )
				{
					state = ST_IDLE;
				}
			}
		break;
		default:
		break;
		}

		cycle++;
	}
//printf("%s(): end of while loop\n",__func__);

	prev_cycle = curr_cycle;

	return bit;
}

int uart_try_send(char * str)
{ // try sending given string by adding it to the uart_sndbuf, if ever possible.
  // returns 0 of failed to send (nothing added to uart_sndbuf), 1 if all string is sent.

	size_t stsz;
	unsigned int bffree;
	int i;


	if( !str )
		return 0;

	stsz=strlen(str);
	if( !stsz )
		return 0;


	bffree = UART_SNDBF_SIZE - ((uart_sndbf_head - uart_sndbf_tail) & UART_SNDBF_MASK);

	if( stsz<bffree ) // max bytes in fifo 255 (!), not 256
	{
		for(i=0;i<stsz;i++)
		{
			uart_sndbf[uart_sndbf_head] = str[i];
			uart_sndbf_head = (uart_sndbf_head>=(UART_SNDBF_SIZE-1)) ? 0 : (uart_sndbf_head+1);
//printf("%s(): sent byte %c to fifo\n",__func__,str[i]);
		}

		return 1;
	}
	
	return 0;
}
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

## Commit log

2017-04-13 commited project files
    [8048_BOARD.DRL, 8048_BOARD.GBL, 8048_BOARD.GBO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]
2017-04-17 updated README file, added schematics in PDF
    [8048_board.SCH]
